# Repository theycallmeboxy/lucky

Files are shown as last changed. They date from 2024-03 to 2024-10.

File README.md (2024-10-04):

# Lucky
*A 40-49 key 13 column (mostly) ortho keyboard with fun and easy kitting*

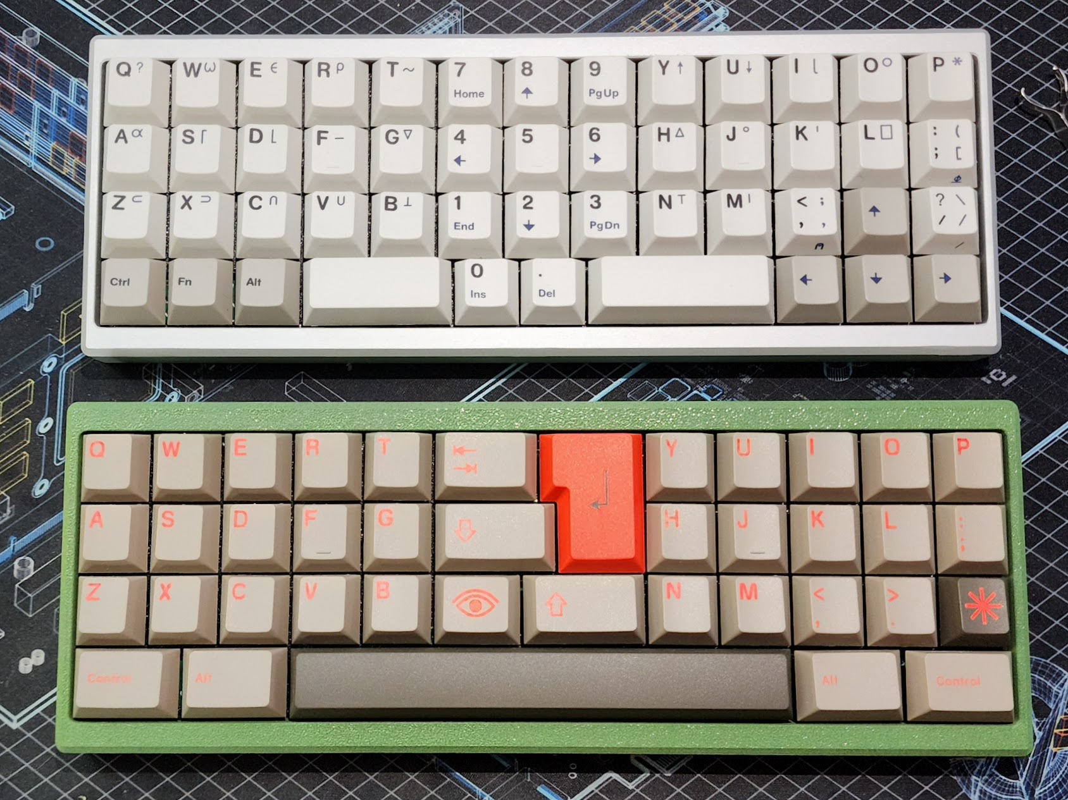
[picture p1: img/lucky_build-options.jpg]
keyborb


**[KLE](https://www.keyboard-layout-editor.com/##@_name=Lucky%2F_vial&author=theycallmeboxy%3B&@=0,0&=0,1&=0,2&=0,3&=0,4&_c=%23ffb5ec%3B&=0,5&=0,6&=0,7&_c=%23cccccc%3B&=0,8&=0,9&=0,10&=0,11&=0,12&_x:0.25&c=%23ffb5ec&w:1.5%3B&=0,5&_x:0.25&w:1.25&h:2&w2:1.5&h2:1&x2:-0.25%3B&=1,7%3B&@_c=%23cccccc%3B&=1,0&=1,1&=1,2&=1,3&=1,4&_c=%23ffb5ec%3B&=1,5&=1,6&=1,7&_c=%23cccccc%3B&=1,8&=1,9&=1,10&=1,11&=1,12&_x:0.25&c=%23ffb5ec&w:1.75%3B&=1,5%3B&@_c=%23cccccc%3B&=2,0&=2,1&=2,2&=2,3&=2,4&_c=%23ffb5ec%3B&=2,5&=2,6&=2,7&_c=%23cccccc%3B&=2,8&=2,9&=2,10&=2,11&=2,12&_x:0.25&c=%23ffb5ec&w:1.25%3B&=2,5&_w:1.75%3B&=2,7%3B&@_c=%23ffba9c%3B&=3,0&=3,1&=3,2&_c=%23fffaa8&w:2.25%3B&=3,4&=3,5&=3,7&_w:2.75%3B&=3,8&_c=%23a6ffdf%3B&=3,10&=3,11&=3,12%3B&@_y:0.25&c=%23ffba9c&w:1.5%3B&=3,0&_w:1.5%3B&=3,2&_c=%23fffaa8&w:2.75%3B&=3,4&=3,5&=3,7&_w:2.25%3B&=3,8&_c=%23a6ffdf&w:1.5%3B&=3,10&_w:1.5%3B&=3,12%3B&@_y:0.25&x:3&c=%23fffaa8&w:7%3B&=3,5)**

## Production Files:

*(Click a link then click download icon in the top right to save a given file to your computer.)*

> [!CAUTION]
> I will assume no responsibility for any cost, damage, or sads resulting from trying to make one of my dumb projects. This project has no implicit support, neither moral nor technical.
> 
> **I'm not a doctor. This is not medical advice. I'm also only a network engineer. You assume all liability in using or reproducing these files.**

3DP Case:
- [Bottom case .stl file](https://github.com/theycallmeboxy/lucky/blob/main/models/draft%201/3dp/Bottom%20Case.stl)
- [Top case .stl file](https://github.com/theycallmeboxy/lucky/blob/main/models/draft%201/3dp/Top%20Case.stl)

CNC Case:
- [Bottom case .step file](https://github.com/theycallmeboxy/lucky/blob/main/models/draft%201/cnc/Bottom%20Case.step)
- [Top case .step file](https://github.com/theycallmeboxy/lucky/blob/main/models/draft%201/cnc/Top%20Case.step)
- [Top case thread drawing .pdf file](https://github.com/theycallmeboxy/lucky/blob/main/models/draft%201/cnc/Top%20Case%20Drawing.pdf)

Plate:
- [Plate .dxf file](https://github.com/theycallmeboxy/lucky/blob/main/models/draft%201/plate/1.6mm%20plate.dxf)

PCB:
> [!WARNING]
> Please note there is a defect in PCB version 1 resulting is a missing
> column wire requiring a bodge; version 1.1 fixes this but has not yet been produced.  If by an act of God you have a v1 PCB here are the [bodge instructions](https://github.com/theycallmeboxy/lucky/blob/main/img/bodge-instructions.png).

- [PCB gerbers .zip file](https://github.com/theycallmeboxy/lucky/blob/main/pcb/lucky%20v1.1/production/lucky1.1.zip)
- [BOM .csv file](https://github.com/theycallmeboxy/lucky/blob/main/pcb/lucky%20v1.1/production/bom.csv)
- [Positions .csv file](https://github.com/theycallmeboxy/lucky/blob/main/pcb/lucky%20v1.1/production/positions.csv)

Firmware:
- [VIAL Firmware .bin file](https://github.com/theycallmeboxy/lucky/blob/main/firmware/vial/binary/boxy_lucky_vial.bin)
  
## Build Notes:

I have made with FDM and CNC aluminum to good effect.

You will need some hardware for either draft 1 case...

**For both versions:**
 
  - 10 m2x6mm flat screws [such as these     ](https://www.amazon.com/gp/product/B000NHYRAY/)
    
   - 16 20mmx3mm gaskets, either 2mm thick foam   [like    these](https://www.aliexpress.us/item/3256805527606478.html)  or
    1.5mm thick silicone   [like these](https://www.aliexpress.us/item/3256802713311572.html)
    
   - 4 SKUF feet like these  [like    these](https://keeb.io/products/skuf-silicone-rubber-keyboard-feet)
 
 **For the 3dp version:**
 
  - 10 m2x3mmx3.5mm heat set inserts   [such as    these](https://www.amazon.com/gp/product/B0C1ND29M7/)

 1. Install heatset inserts, if applicable.   
 2. Apply feet to the cutouts.
 3. Install stabs if you're into that. 
 4. Install switches into the plate and PCB.
 5. Solder it up.
 6. Gaskets on both sides of the plate tabs.
 7. Screw it together from the bottom.

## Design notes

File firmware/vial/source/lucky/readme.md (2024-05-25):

# lucky

lucky

*A short description of the keyboard/project*

* Keyboard Maintainer: [theycallmeboxy](https://github.com/theycallmeboxy)
* Hardware Supported: *The PCBs, controllers supported*
* Hardware Availability: *Links to where you can find this hardware*

Make example for this keyboard (after setting up your build environment):

    make lucky:default

Flashing example for this keyboard:

    make lucky:default:flash

See the [build environment setup](https://docs.qmk.fm/#/getting_started_build_tools) and the [make instructions](https://docs.qmk.fm/#/getting_started_make_guide) for more information. Brand new to QMK? Start with our [Complete Newbs Guide](https://docs.qmk.fm/#/newbs).

## Bootloader

Enter the bootloader in 3 ways:

* **Bootmagic reset**: Hold down the key at (0,0) in the matrix (usually the top left key or Escape) and plug in the keyboard
* **Physical reset button**: Briefly press the button on the back of the PCB - some may have pads you must short instead
* **Keycode in layout**: Press the key mapped to `QK_BOOT` if it is available

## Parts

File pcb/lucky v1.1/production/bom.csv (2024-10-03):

Designator | Footprint | Quantity | Value | LCSC Part #
BOOT1, RST1 | SW_SPST_TL3342 | 2 | SW_SPST | C318884
C1, C3, C4, C5, C6, C7, C8 | 0402 | 7 | 100nF | C1525
C10, C9 | 0402 | 2 | 1uF | C52923
C2 | 0603 | 1 | 10uF | C19702
D1, D10, D11, D12, D13, D14, D15, D16, D17, D18, D19, D2, D20, D21, D22, D23, D24, D25, D26, D27, D28, D29, D3, D30, D31, D32, D33, D34, D35, D36, D37, D38, D39, D4, D40, D41, D42, D43, D44, D45, D46, D47, D48, D49, D5, D6, D7, D8, D9 | D_SOD-123 | 49 | D_Small | C81598
F1 | 1206 | 1 | 500mA | C369160
J1 | USB_C_Receptacle_HRO_TYPE-C-31-M-12 | 1 | USB_C_Receptacle_USB2.0 | C165948
R1, R2, R3, R4 | 0402 | 4 | 5.1k | C25905
U1 | LQFP-48_7x7mm_P0.5mm | 1 | STM32F072CBT6 | C81720
U2 | SOT-143 | 1 | PRTR5V0U2X | C2827688
U3 | SOT-23 | 1 | XC6206PxxxMR-Regulator_Linear | C5446

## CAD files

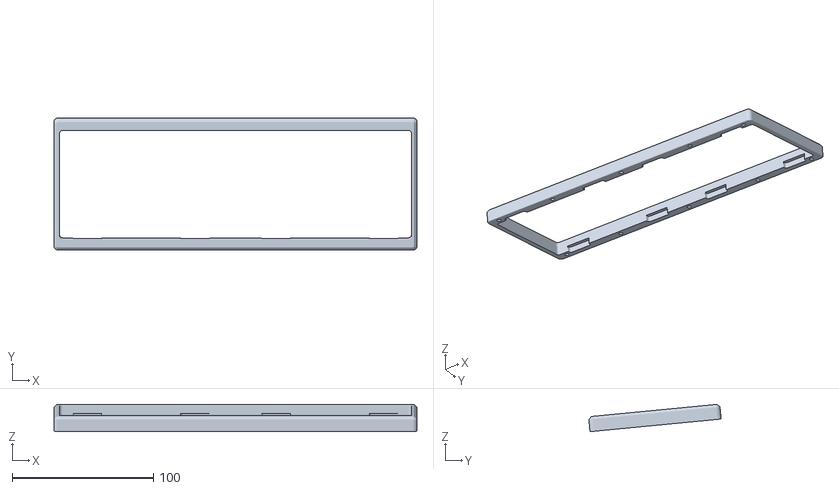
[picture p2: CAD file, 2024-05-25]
models/draft 1/3dp/Top Case.stl
256.7 x 93.6 x 19.3

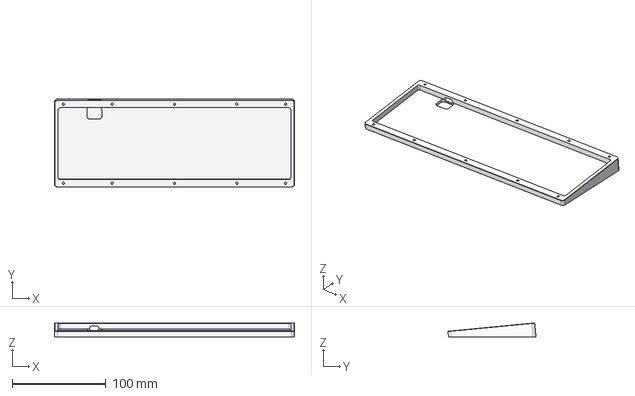
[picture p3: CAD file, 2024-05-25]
models/draft 1/cnc/Bottom Case.step
256.7 x 94.2 x 15.1 mm

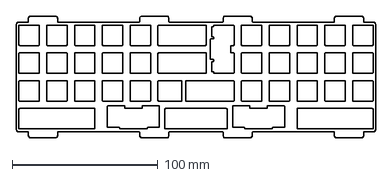
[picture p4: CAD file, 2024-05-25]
models/draft 1/plate/1.6mm plate.dxf
246.6 x 83.3 mm

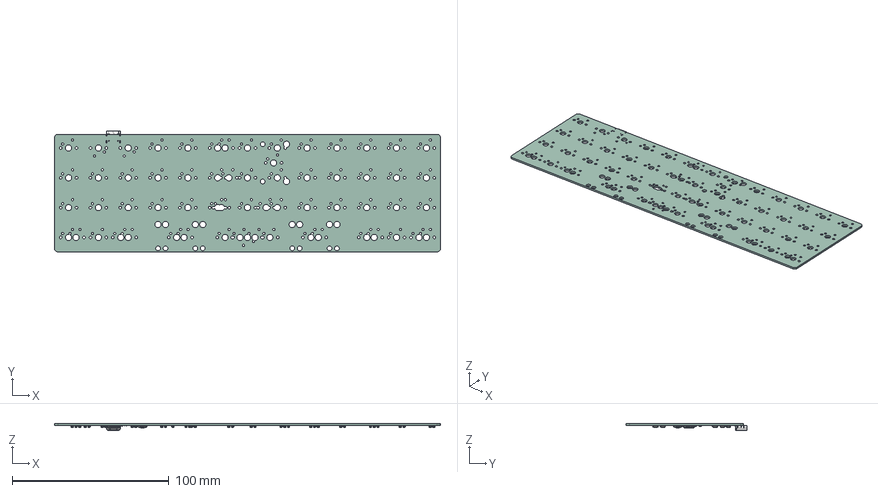
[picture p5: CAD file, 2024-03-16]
models/pcb/lucky prototype 1.step
246.6 x 77.2 x 4.45 mm
D_SOD_123 x 49
C_0402_1005Metric x 9
LQFP_48_7x7mm_P05mm
SW_SPST_TL3342 x 2
SOT_143
SOT_23
R_0402_1005Metric x 4
Fuse_1206_3216Metric
CON_TYPE-C-31-M-12 v0
C_0603_1608Metric
Lucky_PCB

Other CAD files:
models/draft 1/3dp/Bottom Case.stl
models/draft 1/cnc/Top Case.step

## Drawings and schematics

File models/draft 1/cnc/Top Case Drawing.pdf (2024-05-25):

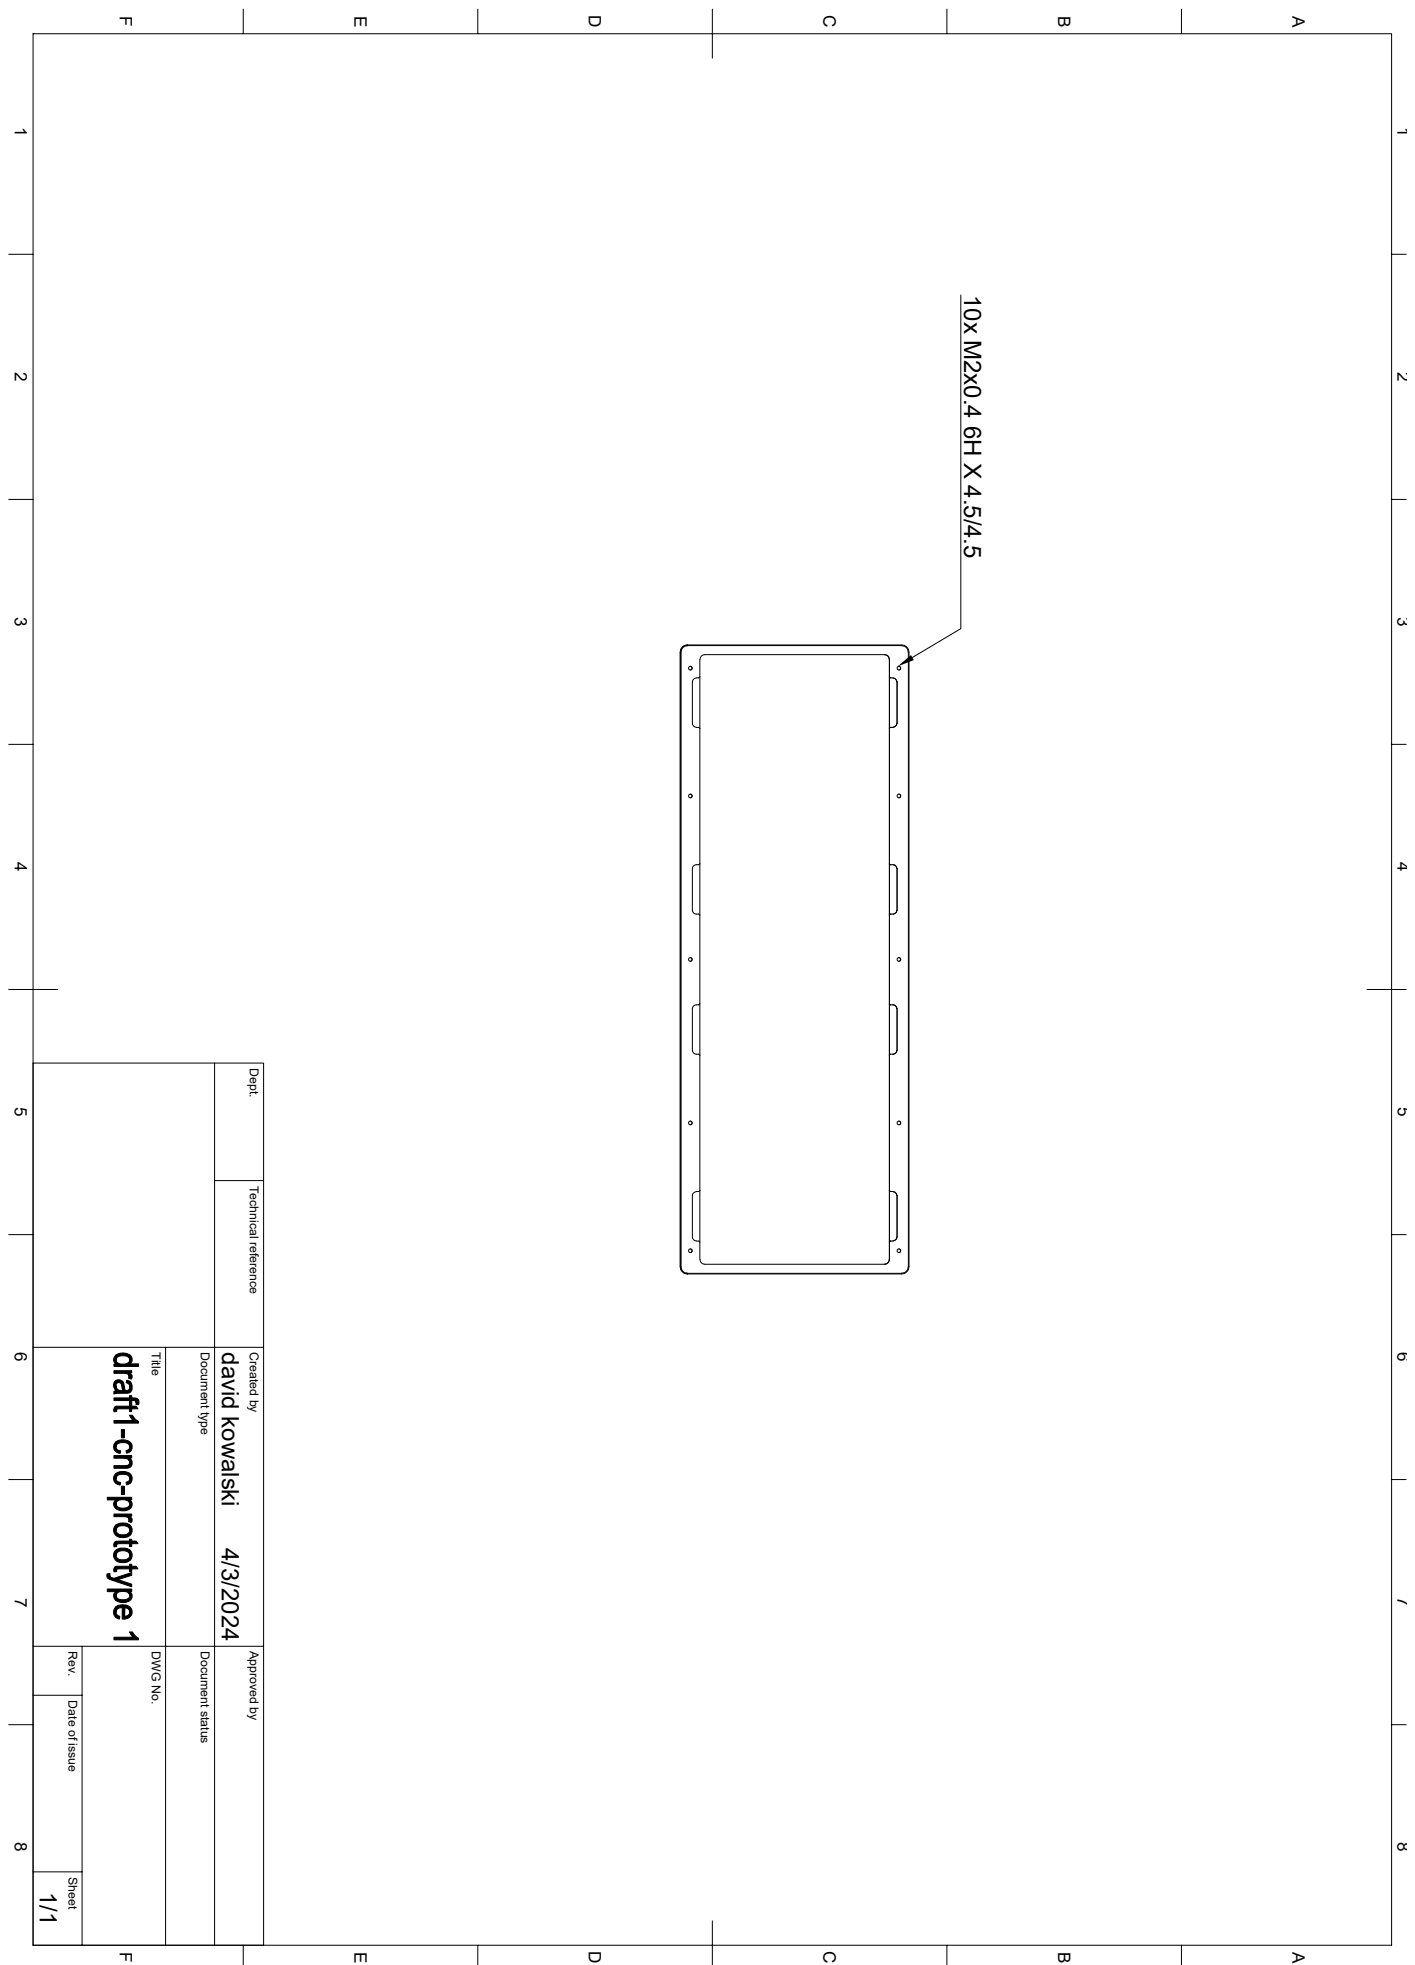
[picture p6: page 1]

1 A 2 3 4 5 6 7 8 1 2 3 4 5 6 7 8 FEDCB FEDCBA Dept. Technical reference Created by Approved by Title DWG No. Document type Document status Rev. Date of issue Sheet 4/3/2024 1/1 david kowalski 10x M2x0.4 6H X 4.5/4.5

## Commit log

2024-03-16 Add Prototype 1 PCB
    [Lucky.kicad_sch, bom.csv, designators.csv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]
2024-03-16 make step
    [lucky prototype 1.step]
2024-05-25 update lucky
    [Lucky.kicad_sch, bom.csv, designators.csv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]
2024-05-25 add/clean up models
    [1.6mm plate.dxf, Bottom Case.step, Bottom Case.stl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]
2024-10-03 add fixed pcb
    [Lucky.kicad_sch, bom.csv, designators.csv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]
